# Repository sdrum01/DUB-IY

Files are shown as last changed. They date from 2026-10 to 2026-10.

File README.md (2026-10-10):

# DUB-IY Dub Siren with RP2040 CPU

## Repository to collect electronic and CAD/CAM Stuff

This repository belongs to the project [*DUBSIREN_rp2040*](https://github.com/sdrum01/dubsiren_rp2040), whitch contains the firmware of the DUB-IY.

Dub sirens are simple synthesizers without VCA (Voltage Controlled Amplifier) or VCF (Voltage Controlled Filter), but usually with a VCO (Voltage Controlled Oscillator) modulated by an LFO (Low Frequency Generator).

Such sirens are typically built with analog circuits. The challenge, however, was to optimize the parameter storage of digital solutions, simplify the electronics and to make it hackable.

**DUB-IY** is based on a Raspberry Pi Pico with an RP2040 CPU. It is fast enough to emulate VCOs and LFOs and offers sufficient options for internal data storage.

The Dub siren creates an square wave signal with an adjustable duty cycle. The sound can be modulated by two LFOs and an envelope generator to modulate the timing parameter. 

Finally, the signal is perfected with an integrated echo effect. 

The following values can be adjusted using potentiometers and switches:

* LFO1 waveform
(square, triple square, triangle, sawtooth, pulse)
* LFO2 waveform (square, triangle, sawtooth)
* Oscillator base frequency
* LFO1 and LFO2 frequency
* LFO1 and LFO2 contribution (negative and positive)
* Timing envelope contribution
* Oscillator waveform duty cycle
* LFO start retriggering
* Delay time (echo)
* Feedback (echo)
* Overall volume

The combination of LFOs 1 and 2 already produces many experimental siren sounds,
but the timing envelope adds significantly more dynamics to the sound.

>[!NOTE]
   >
   >This is a non-profit project with no goal of making big money.
   >It's purely for fun, and we assume no liability!
   
## Waiting List

To reserve one device or PCB pls write me an email: dub-iy@sdrum.elementfx.com

## Documentation

Have a look into the short introduction on YouTube:

- [DUB-IY Introduction](https://youtu.be/Yc06HZqR8gg?si=ktLNwQYJj4XRiWYL)

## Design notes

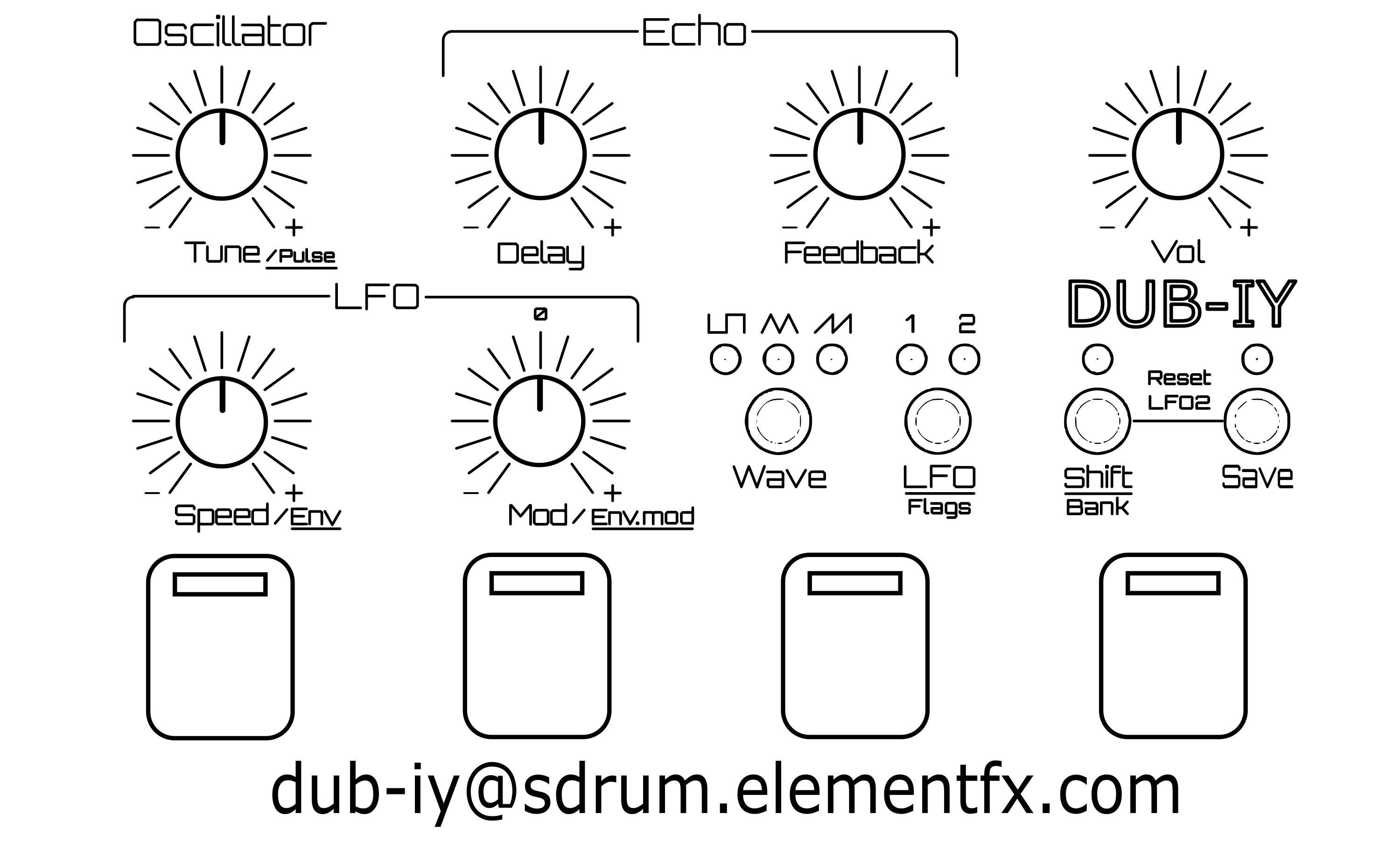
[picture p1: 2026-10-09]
CAD/DXF/Front_DUBIY_mit_Beschriftung_buisnesscard_v3.png

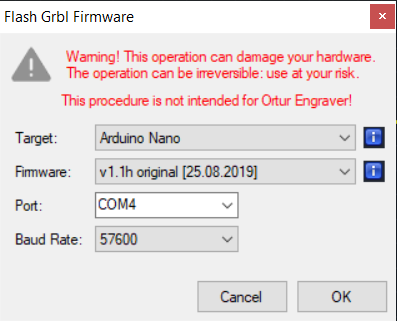
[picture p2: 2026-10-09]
CAD/CAM/LaserGRBL/flash_firmware.png

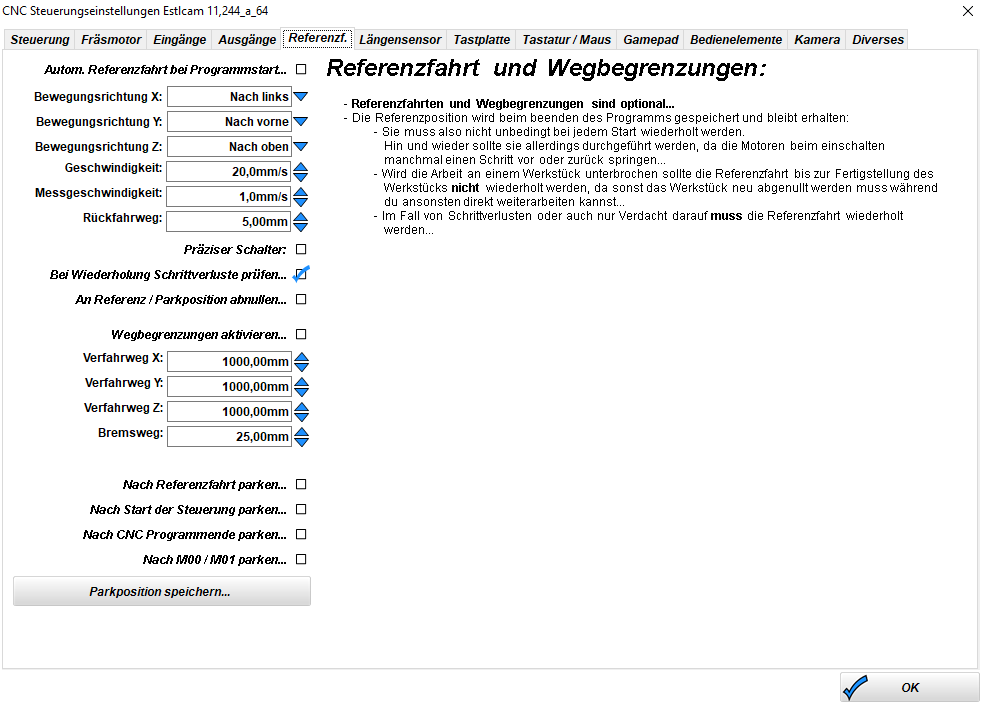
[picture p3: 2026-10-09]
CAD/CAM/Settings_Fräser_ref.png

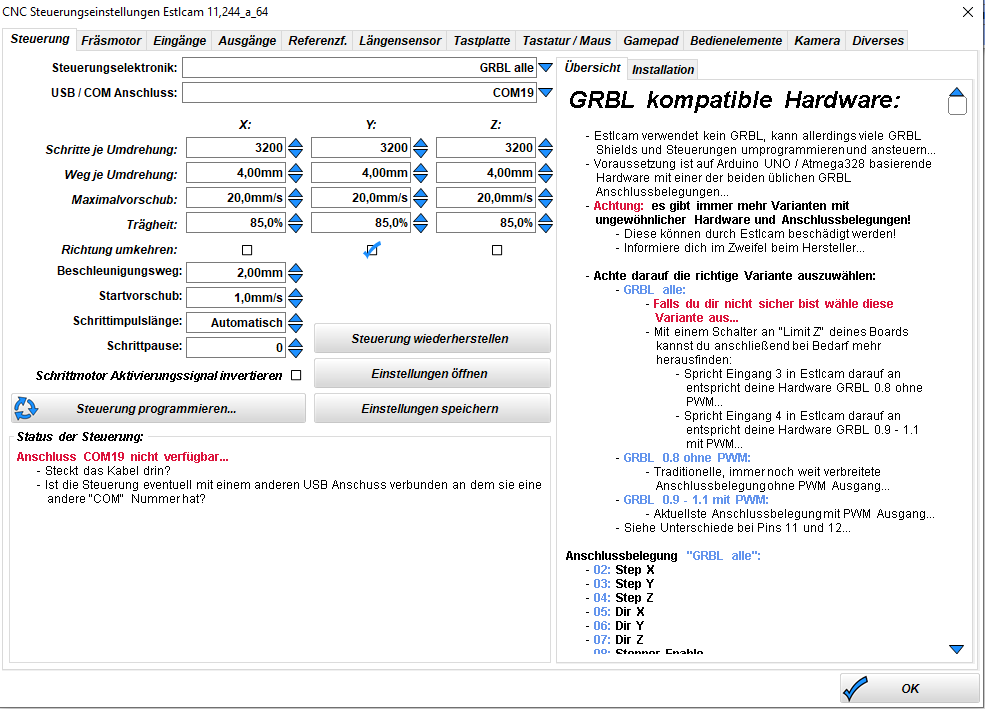
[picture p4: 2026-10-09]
CAD/CAM/Settings_Fräser.png

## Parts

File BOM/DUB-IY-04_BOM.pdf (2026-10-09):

Reference | Value | Datasheet Footprint | Qty
A1 | RaspberryPi-Pico | https://datasheets.raspberrypi.com/pico/pico-datasheet.pdf MCU_RaspberryPi_and_Boards:RPi_Pico_SMD_TH 1
C1,C8 | 100µ | ~ | Capacitor_SMD:CP_Elec_6.3x5.8 | 2
C2,C3,C4,C5,C6,C7,C10,C14,C15 | 100n | ~ | -- verschiedene Werte -- | 9
C9 | 47µ | ~ | Capacitor_SMD:CP_Elec_6.3x5.3 | 1
C11,C20 | 560pF | ~ | Capacitor_SMD:C_0805_2012Metric_Pad1.18x1.45mm_HandSolder 2
C12 | 3,9nF | ~ | Capacitor_SMD:C_0805_2012Metric_Pad1.18x1.45mm_HandSolder 1
C13 | 68nF | ~ | Capacitor_SMD:C_0805_2012Metric_Pad1.18x1.45mm_HandSolder 1
C16 | 3,3nF | ~ | Capacitor_SMD:C_0805_2012Metric_Pad1.18x1.45mm_HandSolder 1
C17,C18 | 4,7µ | ~ | Capacitor_Tantalum_SMD:CP_EIA-2012-12_Kemet-R_Pad1.30x1.05mm_HandSolder 2
C19 | 10n | ~ | Capacitor_SMD:C_0805_2012Metric_Pad1.18x1.45mm_HandSolder 1
C21,C23 | 10µ | ~ | Capacitor_SMD:CP_Elec_4x5.7 | 2
C22 | 82nF | ~ | Capacitor_SMD:C_0805_2012Metric_Pad1.18x1.45mm_HandSolder 1
C24 | 220n | ~ | Capacitor_SMD:C_1206_3216Metric 1
D1 | LED LFO2 | ~ | LED_THT:LED_D3.0mm | 1
D2 | LED LFO1 | ~ | LED_THT:LED_D3.0mm | 1
D3 | LED Shift1 | ~ | LED_THT:LED_D3.0mm | 1
D4 | LED Fire1 | ~ | LED_THT:LED_D3.0mm | 1
D5 | LED Fire2 | ~ | LED_THT:LED_D3.0mm | 1
D6 | LED Fire3 | ~ | LED_THT:LED_D3.0mm | 1
D7 | LED Fire4 | ~ | LED_THT:LED_D3.0mm | 1
D8 | LED_WF_Squ | ~ | LED_THT:LED_D3.0mm | 1
D9 | LED Shift2 | ~ | LED_THT:LED_D3.0mm | 1
D10 | LED_WF_Tri | ~ | LED_THT:LED_D3.0mm | 1
D11 | LED_WF_Saw | ~ | LED_THT:LED_D3.0mm | 1
D20 | SK110 | ~ | Diode_SMD:D_SMA-SMB_Universal_Handsoldering 1
J1 | AudioJack3_Ground ~ | Audiosockets:Jack_3.5mm_Ledino_KB3SPRS_Horizontal 1
J2 | Power Jack | ~ | Connector_BarrelJack:BarrelJack_GCT_DCJ200-10-A_Horizontal 1
R2,R3,R7,R8,R9,R10,R11,R12,R16,R17,R18 | 680 ~ | Resistor_SMD:R_1206_3216Metric 11
R4,R5,R6 | 1k | ~ | Resistor_SMD:R_1206_3216Metric | 3
R19,R27 | 4,7k | ~ | Resistor_SMD:R_1206_3216Metric | 2
R20,R21,R26,R28,R29,R30,RV1,RV2,RV3 | 10k | ~ | -- verschiedene Werte -- | 9
R22,R25 | 15k | ~ | Resistor_SMD:R_1206_3216Metric | 2
R23,RV4,RV5 | 100k | ~ | -- verschiedene Werte -- | 3
R24 | 5,6k | ~ | Resistor_SMD:R_1206_3216Metric | 1
RV6 | 50k | ~ | poti_alps:Potentiometer_Alps_RK09K_Single_Vertical 1
SW1 | LFO1/2 | ~ | Button_Switch_THT:SW_PUSH_6mm1
SW2 | Select LFO WaveForm~ | Button_Switch_THT:SW_PUSH_6mm1
SW3 | Fire4 | ~ | Button_Switch_THT:SW_PUSH_6mm1
SW4 | Fire3 | ~ | Button_Switch_THT:SW_PUSH_6mm1
SW5 | Fire2 | ~ | Button_Switch_THT:SW_PUSH_6mm1
SW6 | Fire1 | ~ | Button_Switch_THT:SW_PUSH_6mm1
SW7 | Shift2/Save | ~ | Button_Switch_THT:SW_PUSH_6mm1
SW8 | Shift1 / Select Bank | ~ | Button_Switch_THT:SW_PUSH_6mm1
U2 | PT2399 | Package_DIP:DIP-16_W7.62mm_Socket_LongPads 1
U3 | L7805 | http://www.st.com/content/ccc/resource/technical/document/datasheet/41/4f/b3/b0/12/d4/47/88/CD00000444.pdf/files/CD00000444.pdf/jcr:content/translations/en.CD0000044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 Package_TO_SOT_SMD:TO-252-3_TabPin2 1
Netzteil 12V 0,5A | | | | 1
PCB | | | | 1
Adapter Klinke 3,5mm-6,3mm | | | | 10

DNP Reichelt | EK | EK Summe
RASP PI PICO H | 5,46 | 5,46
FT-V 100U 16 | 0,24 | 0,48
0,02 | 0,18
ELN RVS-16V470MU | 0,10 | 0,10
0,02 | 0,04
0,02 | 0,02
0,02 | 0,02
0,02 | 0,02
KEM X5R0805 4,7U | 0,10 | 0,20
0,02 | 0,02
SMD ELKO 10/16 | 0,04 | 0,08
0,02 | 0,02
0,02 | 0,02
3004Y1D-EHC-B (https://www.reichelt.de/de/de/shop/produkt/led_3mm_bedrahtet_gelb_350_mcd_60_-361904) | 0,08 | 0,08 gelb
3004Y1D-EHC-B (https://www.reichelt.de/de/de/shop/produkt/led_3mm_bedrahtet_gelb_350_mcd_60_-361904) | 0,08 | 0,08 gelb
3004Y1D-EHC-B (https://www.reichelt.de/de/de/shop/produkt/led_3mm_bedrahtet_gelb_350_mcd_60_-361904) | 0,08 | 0,08 gelb
3034B2D-EHD-A | 0,08 | 0,08 blau
3034B2D-EHD-A | 0,08 | 0,08 blau
3034B2D-EHD-A | 0,08 | 0,08 blau
3034B2D-EHD-A | 0,08 | 0,08 blau
3004G6D-EHB-S (https://www.reichelt.de/de/de/shop/produkt/led_3mm_bedrahtet_gruen_200_mcd_60_-361906) | 0,08 | 0,08 grün
3004R2D-EPC-S (https://www.reichelt.de/de/de/shop/produkt/led_3mm_bedrahtet_rot_100_mcd_60_-361901) | 0,15 | 0,15 rot
3004G6D-EHB-S (https://www.reichelt.de/de/de/shop/produkt/led_3mm_bedrahtet_gruen_200_mcd_60_-361906) | 0,08 | 0,08 grün
3004G6D-EHB-S (https://www.reichelt.de/de/de/shop/produkt/led_3mm_bedrahtet_gruen_200_mcd_60_-361906) | 0,08 | 0,08 grün
0,02 | 0,02
EBS 35 | 0,36 | 0,36
CLIFF FCR681465 | 1,10 | 1,10
0,02 | 0,22
0,02 | 0,06
0,02 | 0,04
RK09K113-LIN10K | 0,99 | 8,91
0,02 | 0,04
RK09K113-LIN100K | 0,99 | 2,97
0,02 | 0,02
RK09K113-LIN50K | 0,99 | 0,99
OMR B3F-1002 | 0,29 | 0,29
OMR B3F-1002 | 0,29 | 0,29
RAFI 100.502 | 1,15 | 1,15
RAFI 100.502 | 1,15 | 1,15
RAFI 100.502 | 1,15 | 1,15
RAFI 100.502 | 1,15 | 1,15
OMR B3F-1002 | 0,29 | 0,29
OMR B3F-1002 | 0,29 | 0,29
4,00 | 4,00 CHINA
L78M05CDT STM | 0,21 | 0,21
EA1005BHES1201 oder
YS6V-1200500E | 7,00 | 7,00
10,00 | 10,00
2,00 | 20,00

incl. MWST
SUMME | 69,31 | 82,4789

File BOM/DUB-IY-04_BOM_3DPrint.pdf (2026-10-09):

Position Name | STL File | Filament Color | Filament Material QTY
1 | Body | DIYBody_V12.3.stl | Black | PLA | 1
2 | Body bottom | DIYBodyBottomSlim_V12.3.stl | Black | PLA | 1
3 | Functionsbuttons / Shift | DIYKnobShift_V12.2_8mm.stl | White | PLA | 4
4 | Fire Button | DIYKnobFire_V12.3.stl | White | PLA | 4
5 | Fire Button extension | DIYKnobFire - Stößel_V12.3_1.stl | White | PLA | 4
6 | Fire Button Inlay | DIYKnobFire - Inlay_V12.3.stl | White | PLA | 4
7 | stribe for Buttons | DIYBodyStreifen.stl | White or Black or whatever | PLA | 1
8 | Potiknob | PotiKnobV25.stl | Black | PLA | 6
9 | Potiknob Inlay | PotiKnob - Inlays_x10_V12.0.stl | Transparent | PLA | 6

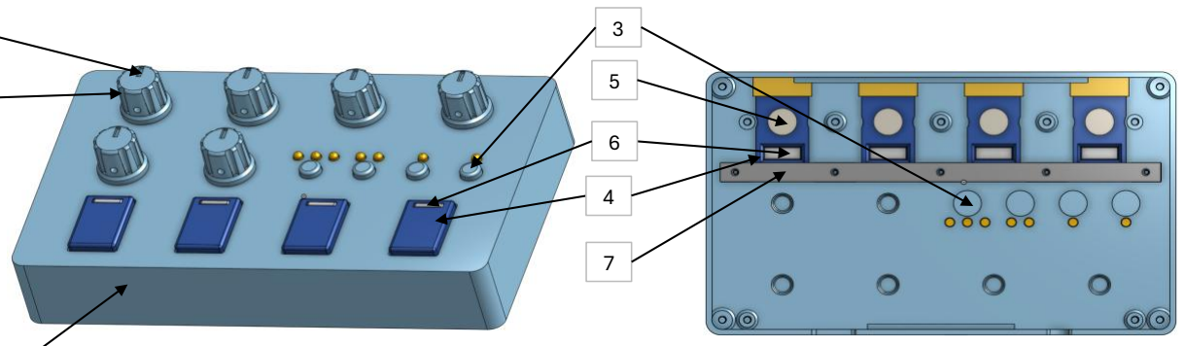
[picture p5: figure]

1 | 2

8

9

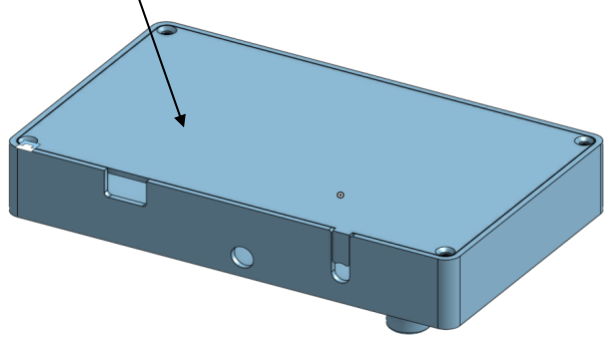
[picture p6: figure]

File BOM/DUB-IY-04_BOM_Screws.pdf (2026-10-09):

Reference | Name | Qty Bemerkung | Hersteller Partno. | Conrad Orderno. RS Online
| 1 Gewindestift M2 x 4mm | 6 für Potiknopf | Toolcraft TO-5370165 | 1790055 - NA431-965
2 Zylinderkopf Innensechskantschraube, Stahl schwarz passiviert, M1.6 x 0.35mm, 6mm 5 für Leiste | 304-17-406
| 3 Zylinderkopf Innensechskantschraube, Edelstahl A2 , M3 x 0.5mm, 6mm | 7 Befestigung PCB | | 303-95-067
| 4 Senkkopf Innensechskantschraube, Edelstahl DIN 7991 A4, M3 x 0.5mm, 8mm | 4 Gehäuseschraube | | 304-17-413

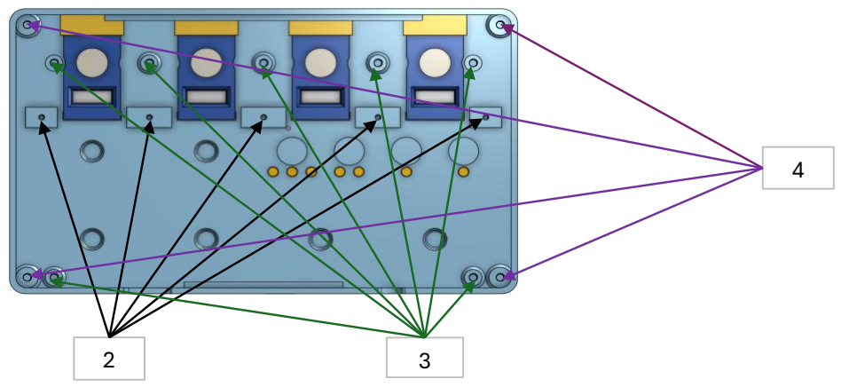
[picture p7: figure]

1

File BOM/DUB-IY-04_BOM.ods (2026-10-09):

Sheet: electronic
Reference | Value | Datasheet | Footprint | Qty | DNP | Reichelt | EK | EK Summe
A1 | RaspberryPi-Pico | https://datasheets.raspberrypi.com/pico/pico-datasheet.pdf | MCU_RaspberryPi_and_Boards:RPi_Pico_SMD_TH | 1 |  | RASP PI PICO H | 5,46 | 5,46
C1,C8 | 100µ | ~ | Capacitor_SMD:CP_Elec_6.3x5.8 | 2 |  | FT-V 100U 16 | 0,24 | 0,48
C2,C3,C4,C5,C6,C7,C10,C14,C15 | 100n | ~ | -- verschiedene Werte -- | 9 |  |  | 0,02 | 0,18
C9 | 47µ | ~ | Capacitor_SMD:CP_Elec_6.3x5.3 | 1 |  | ELN RVS-16V470MU | 0,10 | 0,10
C11,C20 | 560pF | ~ | Capacitor_SMD:C_0805_2012Metric_Pad1.18x1.45mm_HandSolder | 2 |  |  | 0,02 | 0,04
C12 | 3,9nF | ~ | Capacitor_SMD:C_0805_2012Metric_Pad1.18x1.45mm_HandSolder | 1 |  |  | 0,02 | 0,02
C13 | 68nF | ~ | Capacitor_SMD:C_0805_2012Metric_Pad1.18x1.45mm_HandSolder | 1 |  |  | 0,02 | 0,02
C16 | 3,3nF | ~ | Capacitor_SMD:C_0805_2012Metric_Pad1.18x1.45mm_HandSolder | 1 |  |  | 0,02 | 0,02
C17,C18 | 4,7µ | ~ | Capacitor_Tantalum_SMD:CP_EIA-2012-12_Kemet-R_Pad1.30x1.05mm_HandSolder | 2 |  | KEM X5R0805 4,7U | 0,10 | 0,20
C19 | 10n | ~ | Capacitor_SMD:C_0805_2012Metric_Pad1.18x1.45mm_HandSolder | 1 |  |  | 0,02 | 0,02
C21,C23 | 10µ | ~ | Capacitor_SMD:CP_Elec_4x5.7 | 2 |  | SMD ELKO 10/16 | 0,04 | 0,08
C22 | 82nF | ~ | Capacitor_SMD:C_0805_2012Metric_Pad1.18x1.45mm_HandSolder | 1 |  |  | 0,02 | 0,02
C24 | 220n | ~ | Capacitor_SMD:C_1206_3216Metric | 1 |  |  | 0,02 | 0,02
D1 | LED LFO2 | ~ | LED_THT:LED_D3.0mm | 1 |  | 3004Y1D-EHC-B (https://www.reichelt.de/de/de/shop/produkt/led_3mm_bedrahtet_gelb_350_mcd_60_-361904) | 0,08 | 0,08 | gelb
D2 | LED LFO1 | ~ | LED_THT:LED_D3.0mm | 1 |  | 3004Y1D-EHC-B (https://www.reichelt.de/de/de/shop/produkt/led_3mm_bedrahtet_gelb_350_mcd_60_-361904) | 0,08 | 0,08 | gelb
D3 | LED Shift1 | ~ | LED_THT:LED_D3.0mm | 1 |  | 3004Y1D-EHC-B (https://www.reichelt.de/de/de/shop/produkt/led_3mm_bedrahtet_gelb_350_mcd_60_-361904) | 0,08 | 0,08 | gelb
D4 | LED Fire1 | ~ | LED_THT:LED_D3.0mm | 1 |  | 3034B2D-EHD-A | 0,08 | 0,08 | blau
D5 | LED Fire2 | ~ | LED_THT:LED_D3.0mm | 1 |  | 3034B2D-EHD-A | 0,08 | 0,08 | blau
D6 | LED Fire3 | ~ | LED_THT:LED_D3.0mm | 1 |  | 3034B2D-EHD-A | 0,08 | 0,08 | blau
D7 | LED Fire4 | ~ | LED_THT:LED_D3.0mm | 1 |  | 3034B2D-EHD-A | 0,08 | 0,08 | blau
D8 | LED_WF_Squ | ~ | LED_THT:LED_D3.0mm | 1 |  | 3004G6D-EHB-S (https://www.reichelt.de/de/de/shop/produkt/led_3mm_bedrahtet_gruen_200_mcd_60_-361906) | 0,08 | 0,08 | grün
D9 | LED Shift2 | ~ | LED_THT:LED_D3.0mm | 1 |  | 3004R2D-EPC-S (https://www.reichelt.de/de/de/shop/produkt/led_3mm_bedrahtet_rot_100_mcd_60_-361901) | 0,15 | 0,15 | rot
D10 | LED_WF_Tri | ~ | LED_THT:LED_D3.0mm | 1 |  | 3004G6D-EHB-S (https://www.reichelt.de/de/de/shop/produkt/led_3mm_bedrahtet_gruen_200_mcd_60_-361906) | 0,08 | 0,08 | grün
D11 | LED_WF_Saw | ~ | LED_THT:LED_D3.0mm | 1 |  | 3004G6D-EHB-S (https://www.reichelt.de/de/de/shop/produkt/led_3mm_bedrahtet_gruen_200_mcd_60_-361906) | 0,08 | 0,08 | grün
D20 | SK110 | ~ | Diode_SMD:D_SMA-SMB_Universal_Handsoldering | 1 |  |  | 0,02 | 0,02
J1 | AudioJack3_Ground | ~ | Audiosockets:Jack_3.5mm_Ledino_KB3SPRS_Horizontal | 1 |  | EBS 35 | 0,36 | 0,36
J2 | Power Jack | ~ | Connector_BarrelJack:BarrelJack_GCT_DCJ200-10-A_Horizontal | 1 |  | CLIFF FCR681465 | 1,10 | 1,10
R2,R3,R7,R8,R9,R10,R11,R12,R16,R17,R18 | 680 | ~ | Resistor_SMD:R_1206_3216Metric | 11 |  |  | 0,02 | 0,22
R4,R5,R6 | 1k | ~ | Resistor_SMD:R_1206_3216Metric | 3 |  |  | 0,02 | 0,06
R19,R27 | 4,7k | ~ | Resistor_SMD:R_1206_3216Metric | 2 |  |  | 0,02 | 0,04
R20,R21,R26,R28,R29,R30,RV1,RV2,RV3 | 10k | ~ | -- verschiedene Werte -- | 9 |  | RK09K113-LIN10K | 0,99 | 8,91
R22,R25 | 15k | ~ | Resistor_SMD:R_1206_3216Metric | 2 |  |  | 0,02 | 0,04
R23,RV4,RV5 | 100k | ~ | -- verschiedene Werte -- | 3 |  | RK09K113-LIN100K | 0,99 | 2,97
R24 | 5,6k | ~ | Resistor_SMD:R_1206_3216Metric | 1 |  |  | 0,02 | 0,02
RV6 | 50k | ~ | poti_alps:Potentiometer_Alps_RK09K_Single_Vertical | 1 |  | RK09K113-LIN50K | 0,99 | 0,99
SW1 | LFO1/2 | ~ | Button_Switch_THT:SW_PUSH_6mm | 1 |  | OMR B3F-1002 | 0,29 | 0,29
SW2 | Select LFO WaveForm | ~ | Button_Switch_THT:SW_PUSH_6mm | 1 |  | OMR B3F-1002 | 0,29 | 0,29
SW3 | Fire4 | ~ | Button_Switch_THT:SW_PUSH_6mm | 1 |  | RAFI 100.502 | 1,15 | 1,15
SW4 | Fire3 | ~ | Button_Switch_THT:SW_PUSH_6mm | 1 |  | RAFI 100.502 | 1,15 | 1,15
SW5 | Fire2 | ~ | Button_Switch_THT:SW_PUSH_6mm | 1 |  | RAFI 100.502 | 1,15 | 1,15
SW6 | Fire1 | ~ | Button_Switch_THT:SW_PUSH_6mm | 1 |  | RAFI 100.502 | 1,15 | 1,15
SW7 | Shift2/Save | ~ | Button_Switch_THT:SW_PUSH_6mm | 1 |  | OMR B3F-1002 | 0,29 | 0,29
SW8 | Shift1 / Select Bank | ~ | Button_Switch_THT:SW_PUSH_6mm | 1 |  | OMR B3F-1002 | 0,29 | 0,29
U2 | PT2399 |  | Package_DIP:DIP-16_W7.62mm_Socket_LongPads | 1 |  |  | 4,00 | 4,00 | CHINA
U3 | L7805 | http://www.st.com/content/ccc/resource/technical/document/datasheet/41/4f/b3/b0/12/d4/47/88/CD00000444.pdf/files/CD00000444.pdf/jcr:content/translations/en.CD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 | Package_TO_SOT_SMD:TO-252-3_TabPin2 | 1 |  | L78M05CDT STM | 0,21 | 0,21
Power Supply 12V 0,5A |  |  |  | 1 |  | EA1005BHES1201 oder YS6V-1200500E | 7,00 | 7,00
PCB |  |  |  | 1 |  |  | 10,00 | 10,00
Adapter Klinke 3,5mm-6,3mm |  |  |  | 10 |  |  | 2,00 | 20,00
 |  |  |  |  |  |  |  |  | incl. MWST
 |  |  |  |  |  |  | SUMME | 69,31 | 82,4789

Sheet: Screws
Reference | Name | Qty | Bemerkung | Hersteller Partno. | Conrad Orderno. | RS Online
1 | Gewindestift M2 x 4mm | 6 | für Potiknopf | Toolcraft TO-5370165 | 1790055 - NA | 431-965
2 | Zylinderkopf Innensechskantschraube, Stahl schwarz passiviert, M1.6 x 0.35mm, 6mm | 5 | für Leiste |  |  | 304-17-406
3 | Zylinderkopf Innensechskantschraube, Edelstahl A2 , M3 x 0.5mm, 6mm | 7 | Befestigung PCB |  |  | 303-95-067
4 | Senkkopf Innensechskantschraube, Edelstahl DIN 7991 A4, M3 x 0.5mm, 8mm | 4 | Gehäuseschraube |  |  | 304-17-413
 | 4
 | 2 3
 | 1

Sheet: 3D-Print
Position | Name | STL File | Filament Color | Filament Material | QTY
1 | Body | DIYBody_V12.3.stl | Black | PLA | 1
2 | Body bottom | DIYBodyBottomSlim_V12.3.stl | Black | PLA | 1
3 | Functionsbuttons / Shift | DIYKnobShift_V12.2_8mm.stl | White | PLA | 4
4 | Fire Button | DIYKnobFire_V12.3.stl | White | PLA | 4
5 | Fire Button extension | DIYKnobFire - Stößel_V12.3_1.stl | White | PLA | 4
6 | Fire Button Inlay | DIYKnobFire - Inlay_V12.3.stl | White | PLA | 4
7 | stribe for Buttons | DIYBodyStreifen.stl | White or Black or whatever | PLA | 1
8 | Potiknob | PotiKnobV25.stl | Black | PLA | 6
9 | Potiknob Inlay | PotiKnob - Inlays_x10_V12.0.stl | Transparent | PLA | 6
9 |  | 3
 |  | 5
8
 |  | 6
 |  | 4
 |  | 7
1 | 2

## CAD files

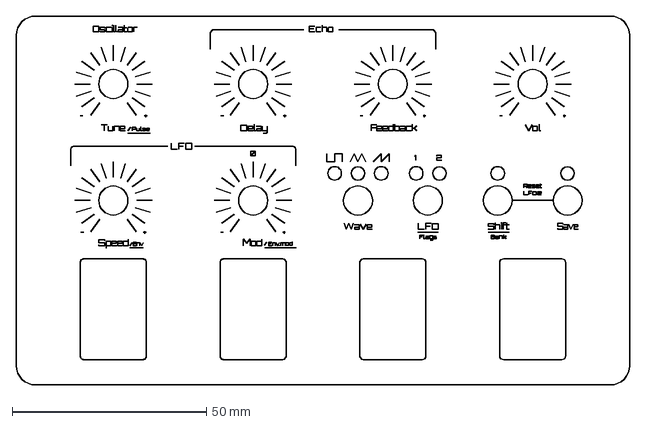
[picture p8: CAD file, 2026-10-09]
CAD/DXF/DIYBody - Frontplatte_EMS_1.dxf
158.0 x 95.0 mm

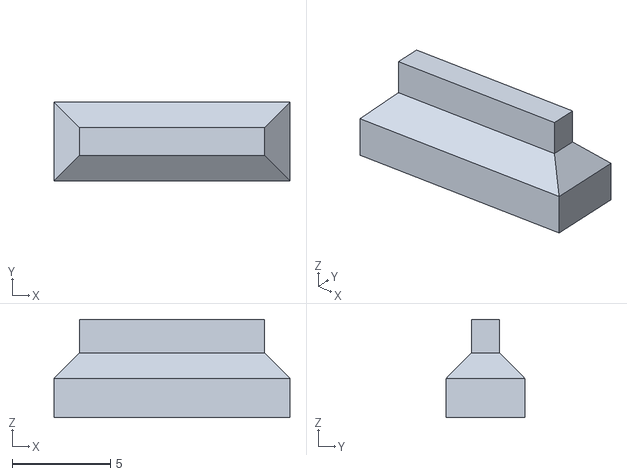
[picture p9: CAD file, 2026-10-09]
CAD/STL/10/DIYKnob Fire - Inlay square.stl
12.0 x 4.00 x 5.00

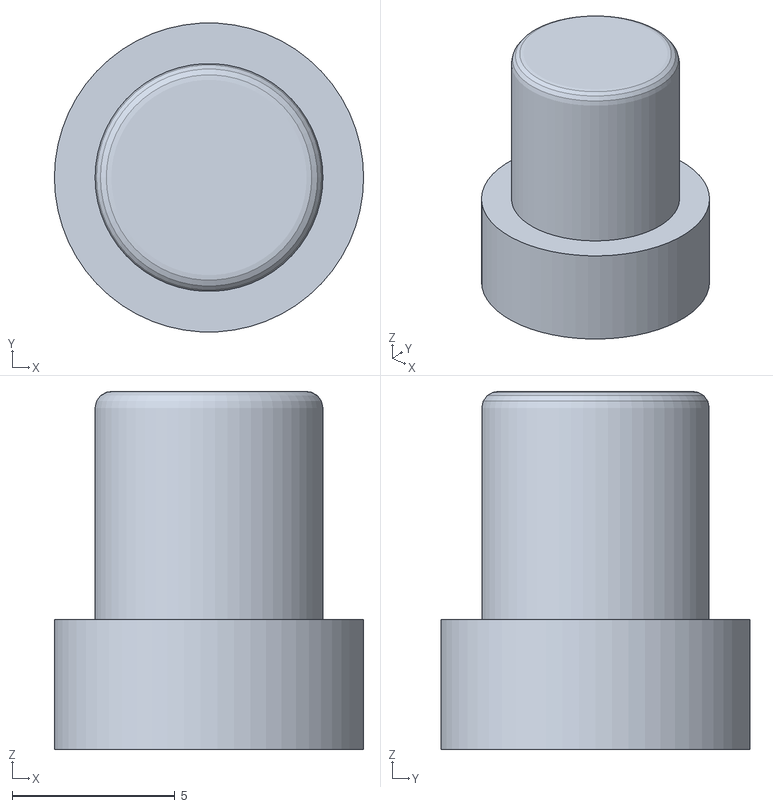
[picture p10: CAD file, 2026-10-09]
CAD/STL/11/DIYKnobShift_V11.3.stl
9.50 x 9.49 x 11.0

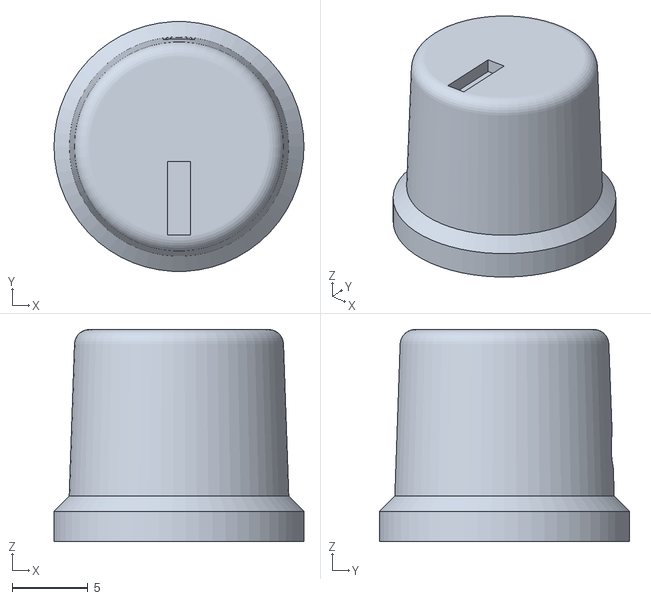
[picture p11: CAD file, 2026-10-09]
CAD/STL/25/PotiKnobV25.stl
16.5 x 16.5 x 14.0

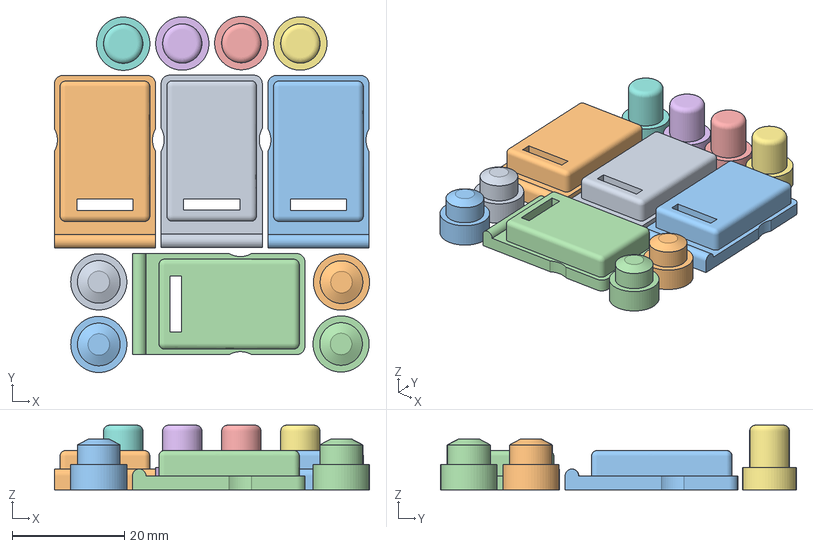
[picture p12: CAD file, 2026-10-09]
CAD/STL/CR10_DIYKnob_V12.3.3mf
56.1 x 63.4 x 11.5 mm
DIYKnobFire_V12.3.stl
DIYKnobFire_V12.3.stl(1)
DIYKnobFire_V12.3.stl(2)
DIYKnobFire_V12.3.stl(3)
DIYKnobShift_V12.2_8mm.stl
DIYKnobShift_V12.2_8mm.stl(1)
DIYKnobShift_V12.2_8mm.stl(2)
DIYKnobShift_V12.2_8mm.stl(3)
DIYKnobFire - Stößel_V12.3.stl
DIYKnobFire - Stößel_V12.3.stl(1)
DIYKnobFire - Stößel_V12.3.stl(2)
DIYKnobFire - Stößel_V12.3.stl(3)

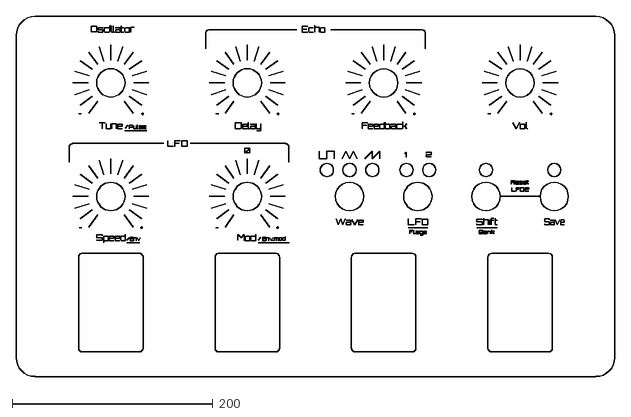
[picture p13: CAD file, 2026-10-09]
CAD/DXF/DIYBody - Frontplatte_EMS.dxf
597.2 x 359.1

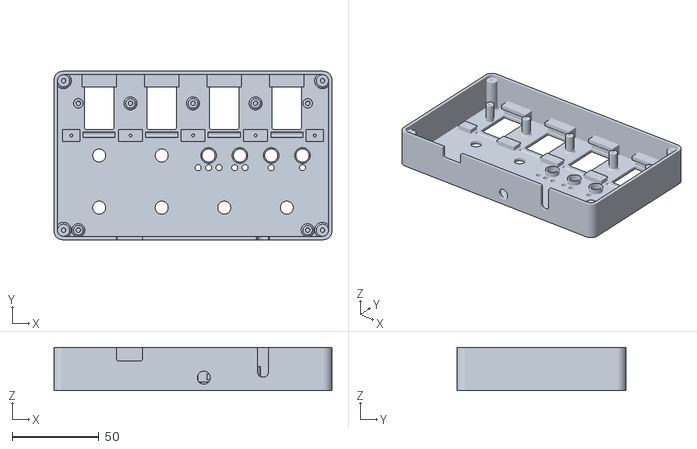
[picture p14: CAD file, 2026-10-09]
CAD/STL/11/DIYBody_V11.1.stl
160.0 x 97.0 x 25.0

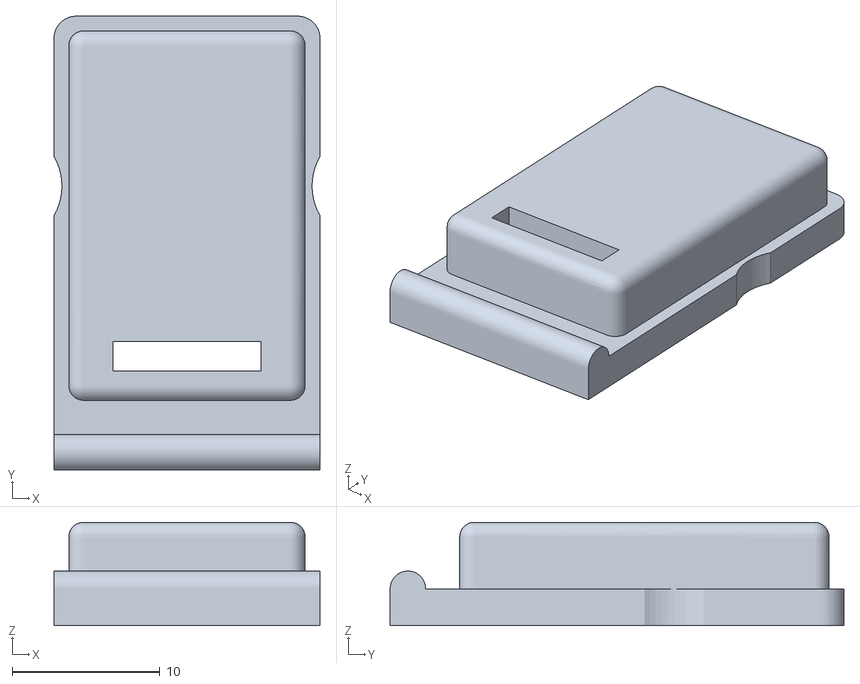
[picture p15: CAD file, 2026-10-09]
CAD/STL/12/DIYKnobFire_V12.3.stl
18.0 x 30.7 x 7.00

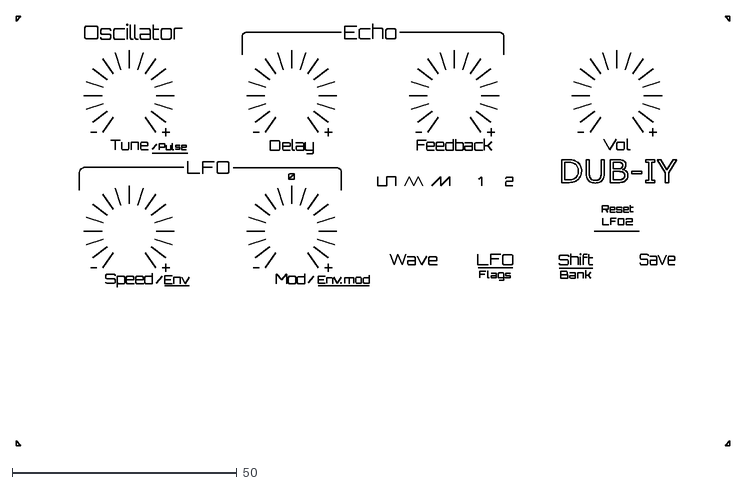
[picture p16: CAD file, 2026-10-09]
CAD/DXF/Frontplatte_EMS_grosse_schriftt_engrave_logo_lasergrbl.dxf
158.9 x 95.5

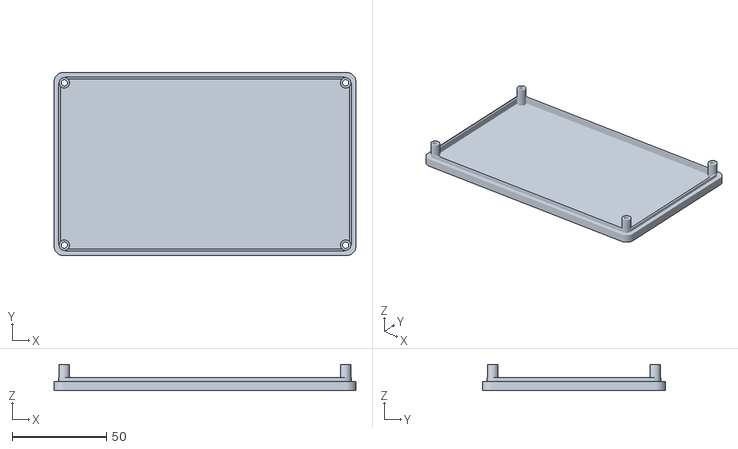
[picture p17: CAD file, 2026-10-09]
CAD/STL/10/DIYDeckel_V10.1.stl
160.0 x 97.0 x 14.0

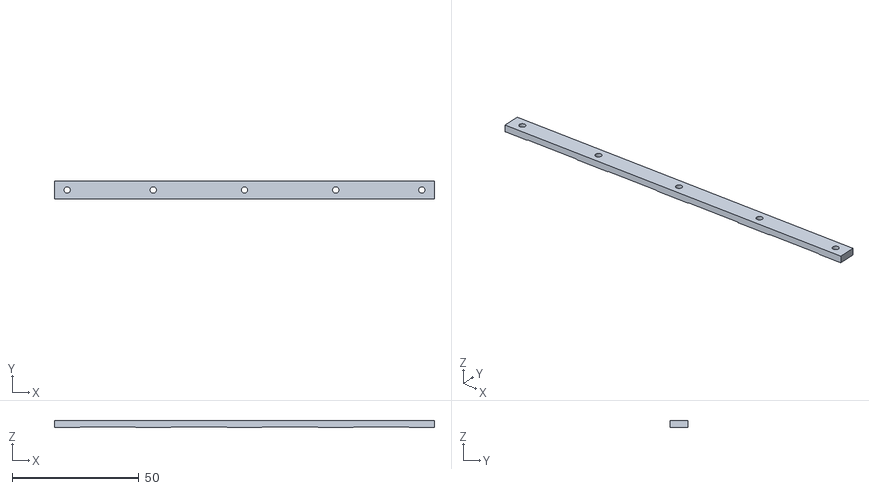
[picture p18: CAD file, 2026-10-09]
CAD/STL/11/DIYStreifen_V11.3.stl
150.0 x 7.00 x 2.70

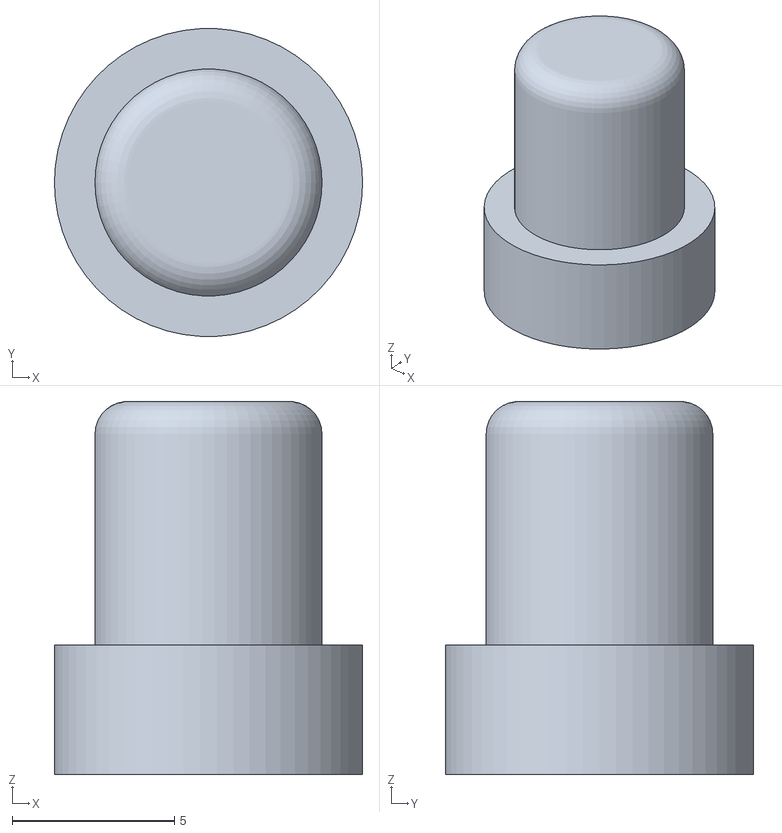
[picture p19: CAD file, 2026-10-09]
CAD/STL/12/DIYKnobShift_V12.2_8mm.stl
9.50 x 9.49 x 11.5

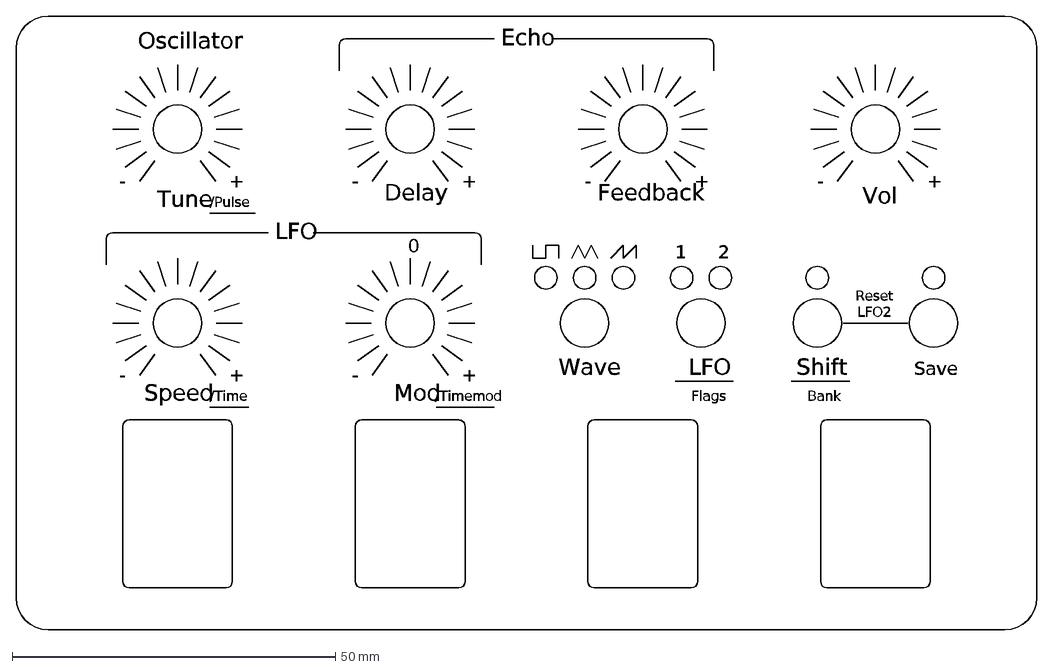
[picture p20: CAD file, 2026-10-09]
CAD/DXF/DIYBody - Frontplatte.dxf
-
+
0
2
1
Speed
Mod
/Time
/Timemod
Wave
LFO
Shift
Tune
Delay
Feedback
/Pulse
Bank
Save
Flags
Reset LFO2
Oscillator
Vol
Echo

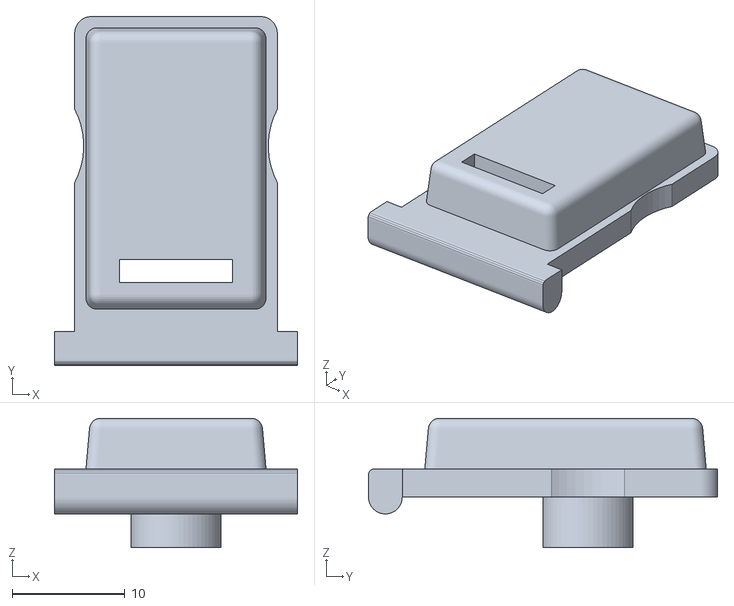
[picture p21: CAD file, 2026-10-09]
CAD/STL/10/DIYKnobFireSquare_V10.1.stl
21.6 x 31.0 x 11.5

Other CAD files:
CAD/STL/10/DIYKnobShift_V10.1.stl
CAD/STL/11/DIYDeckel_V11.4_5mm.stl
CAD/STL/12/DIYBodyBottomSlim_V12.3.stl
CAD/DXF/DIYBody - Frontplatte_EMS_grosse_schrift.dxf
CAD/STL/10/DIYBody_V10.2.stl
CAD/STL/10/DIYStreifen_V10.1.stl
CAD/STL/11/DIYBody - Rahmen.stl
CAD/STL/11/DIYDeckel_V11.1_10mm.stl
CAD/STL/11/DIYDeckel_V11.4_15mm.stl
CAD/STL/11/DIYKnobFireInlaysquare_V11.1.stl
CAD/STL/11/DIYKnobFireStößel_V11.2.stl
CAD/STL/11/DIYKnobFireStößel_V11.3.stl
CAD/STL/11/DIYKnobFiresquare_V11.3.stl
CAD/STL/11/PotiKnob_V11.6.stl
CAD/STL/11/PotiKnob_inlay_V11.6.stl
CAD/STL/12/DIYBodyBottomSlim_V12.1.stl
CAD/STL/12/DIYBodyStreifen.stl
CAD/STL/12/DIYBody_V12.0.stl
CAD/STL/12/DIYBody_V12.2.stl
CAD/STL/12/DIYBody_V12.3.stl
CAD/STL/12/DIYKnobFire - Inlay_V12.3.stl
CAD/STL/12/DIYKnobFire - Stößel_V12.3.stl
CAD/STL/12/DIYKnobFire - Stößel_V12.3_1.stl
CAD/STL/12/PotiKnob - Inlays_x10_V12.0.stl
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

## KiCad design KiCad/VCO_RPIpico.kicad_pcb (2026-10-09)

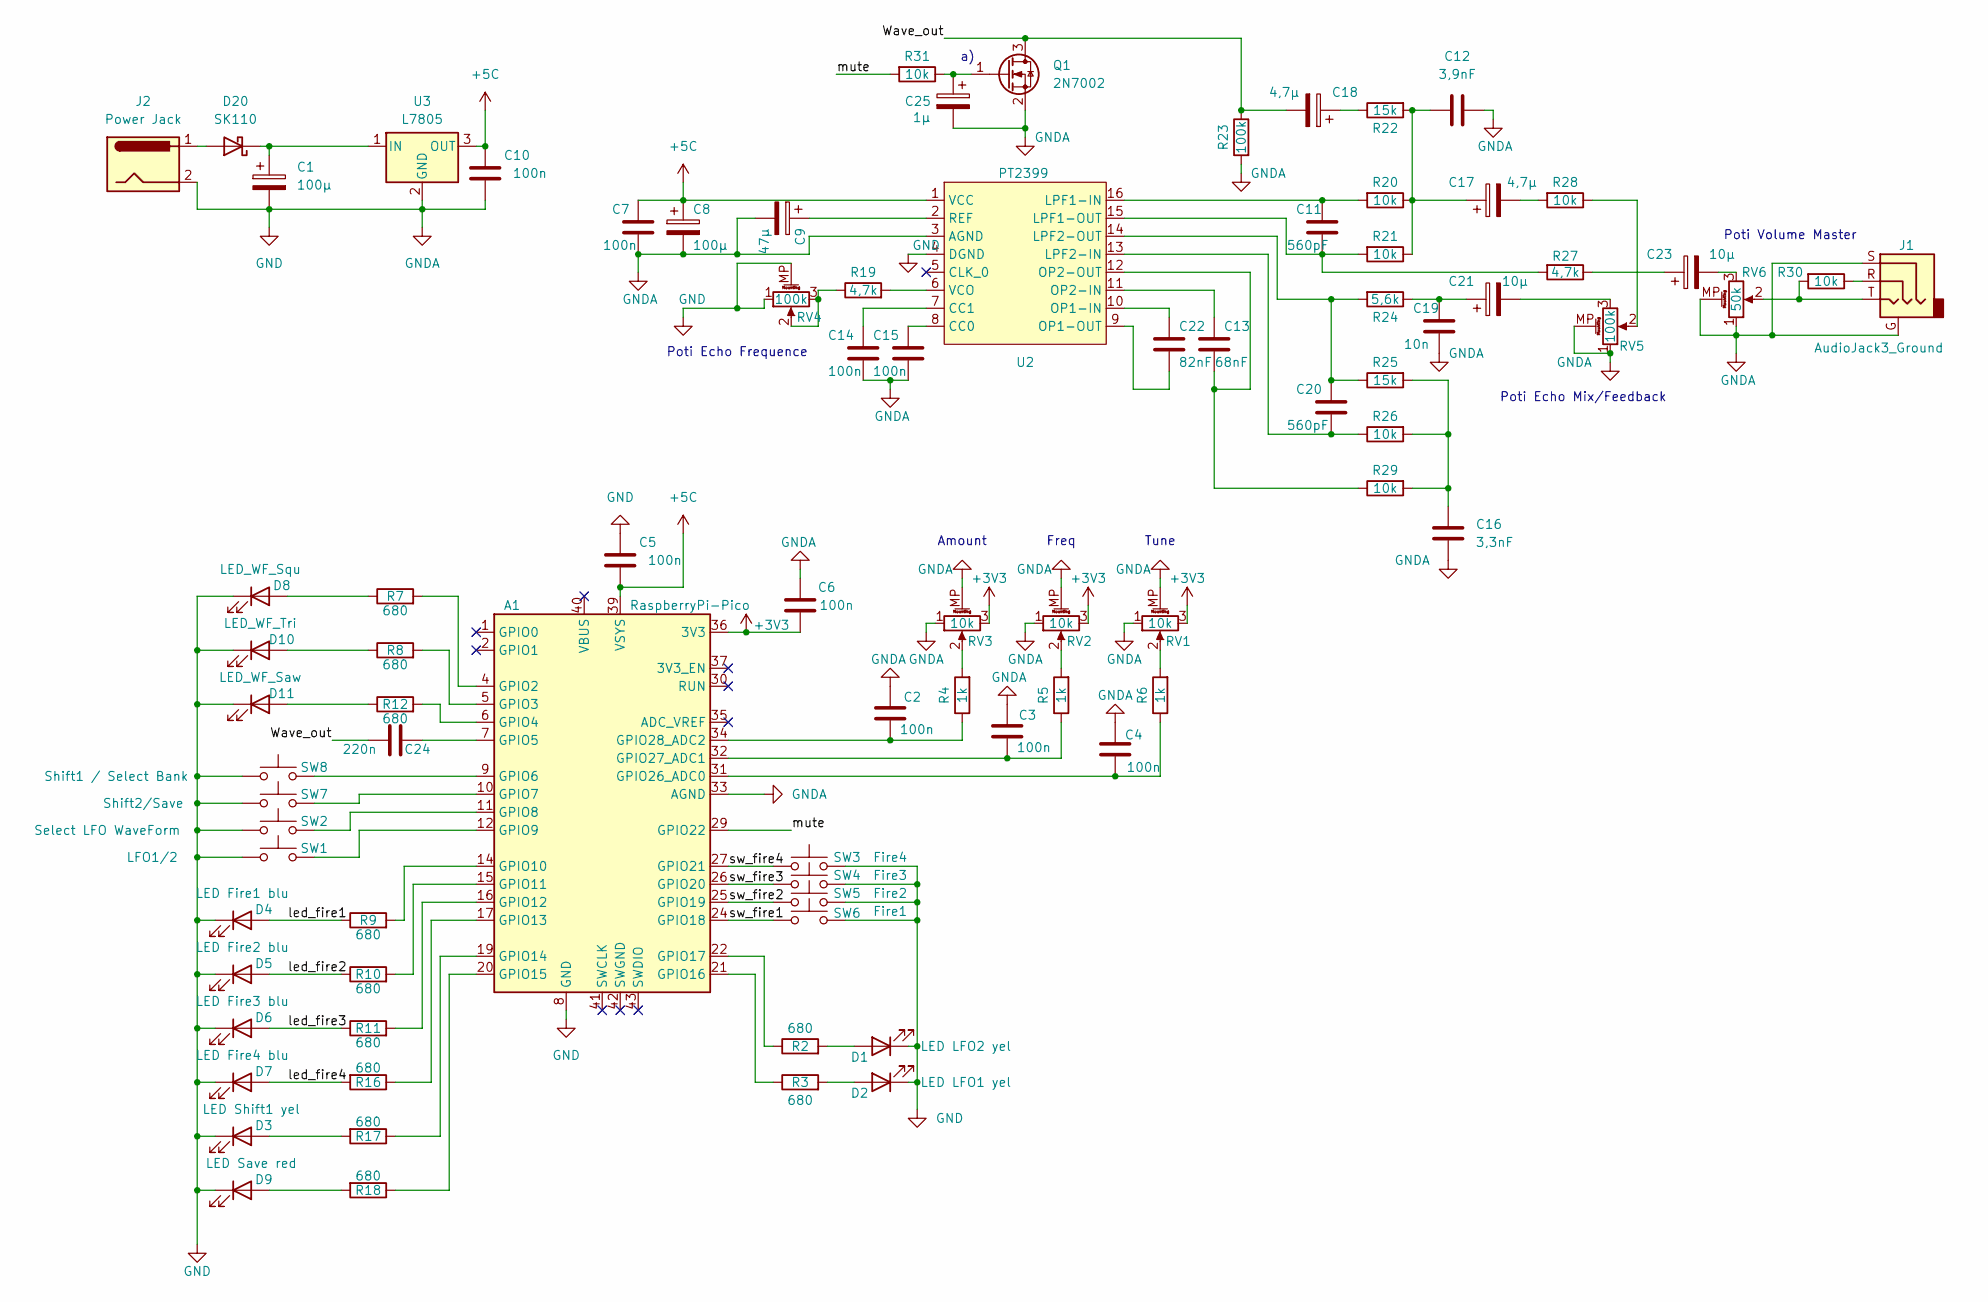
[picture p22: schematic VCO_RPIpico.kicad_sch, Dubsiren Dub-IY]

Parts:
A1: RaspberryPi-Pico; RPi_Pico_SMD_TH
C1, C8: 100µ; CP_Elec_6.3x5.8
C2, C3, C4, C5, C6, C7: 100n; C_1206_3216Metric
C9: 47µ; CP_Elec_6.3x5.3
C10, C14, C15: 100n; C_0805_2012Metric_Pad1.18x1.45mm_HandSolder
C11, C20: 560pF; C_0805_2012Metric_Pad1.18x1.45mm_HandSolder
C12: 3,9nF; C_0805_2012Metric_Pad1.18x1.45mm_HandSolder
C13: 68nF; C_0805_2012Metric_Pad1.18x1.45mm_HandSolder
C16: 3,3nF; C_0805_2012Metric_Pad1.18x1.45mm_HandSolder
C17, C18: 4,7µ; CP_EIA-2012-12_Kemet-R_Pad1.30x1.05mm_HandSolder
C19: 10n; C_0805_2012Metric_Pad1.18x1.45mm_HandSolder
C21, C23: 10µ; CP_Elec_4x5.7
C22: 82nF; C_0805_2012Metric_Pad1.18x1.45mm_HandSolder
C24: 220n; C_1206_3216Metric
C25: 1µ; CP_EIA-2012-12_Kemet-R_Pad1.30x1.05mm_HandSolder
D1: LED LFO2 yel; LED_D3.0mm
D2: LED LFO1 yel; LED_D3.0mm
D3: LED Shift1 yel; LED_D3.0mm
D4: LED Fire1 blu; LED_D3.0mm
D5: LED Fire2 blu; LED_D3.0mm
D6: LED Fire3 blu; LED_D3.0mm
D7: LED Fire4 blu; LED_D3.0mm
D8: LED_WF_Squ; LED_D3.0mm
D9: LED Save red; LED_D3.0mm
D10: LED_WF_Tri; LED_D3.0mm
D11: LED_WF_Saw; LED_D3.0mm
D20: SK110; D_SMA-SMB_Universal_Handsoldering
J1: AudioJack3_Ground; Jack_6.35mm_Neutrik_NMJ6HFD2_Horizontal
J2: Power Jack; BarrelJack_GCT_DCJ200-10-A_Horizontal
Q1: 2N7002; SOT-23
R2, R3, R7, R8, R9, R10, R11, R12, R16, R17, R18: 680; R_1206_3216Metric
R4, R5, R6: 1k; R_1206_3216Metric
R19, R27: 4,7k; R_1206_3216Metric
R20, R21, R26, R28, R29, R30, R31: 10k; R_1206_3216Metric
R22, R25: 15k; R_1206_3216Metric
R23: 100k; R_1206_3216Metric
R24: 5,6k; R_1206_3216Metric
RV1, RV2, RV3: 10k; Potentiometer_Alps_RK09K_Single_Vertical
RV4, RV5: 100k; Potentiometer_Alps_RK09K_Single_Vertical
RV6: 50k; Potentiometer_Alps_RK09K_Single_Vertical
SW1: LFO1/2; SW_PUSH_6mm
SW2: Select LFO WaveForm; SW_PUSH_6mm
SW3: Fire4; SW_PUSH_6mm
SW4: Fire3; SW_PUSH_6mm
SW5: Fire2; SW_PUSH_6mm
SW6: Fire1; SW_PUSH_6mm
SW7: Shift2/Save; SW_PUSH_6mm
SW8: Shift1 / Select Bank; SW_PUSH_6mm
U2: PT2399; DIP-16_W7.62mm_Socket_LongPads
U3: L7805; TO-252-3_TabPin2

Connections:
+3V3: A1.36 (3V3), C6.2, RV1.3, RV2.3, RV3.3
+5C: A1.39 (VSYS), C5.2, C7.1, C8.1, C10.1, U2.1 (VCC), U3.3 (OUT)
/Wave_out: C18.2, C24.1, Q1.3 (D), R23.1
/led_fire1: D4.2 (A), R9.1
/led_fire2: D5.2 (A), R10.1
/led_fire3: D6.2 (A), R11.1
/led_fire4: D7.2 (A), R16.2
/sw_fire1: A1.24 (GPIO18), SW6.1
/sw_fire2: A1.25 (GPIO19), SW5.1
/sw_fire3: A1.26 (GPIO20), SW4.1
/sw_fire4: A1.27 (GPIO21), SW3.1
GND: A1.3 (GND), A1.8 (GND), A1.13 (GND), A1.18 (GND), A1.23 (GND), A1.28 (GND), A1.33 (AGND), A1.38 (GND), C1.2, C2.1, C3.1, C4.1, C5.1, C6.1, C7.2, C8.2, C9.2, C10.2, C12.1, C14.2, C15.2, C16.2, C19.2, C25.2, D1.1 (K), D2.1 (K), D3.1 (K), D4.1 (K), D5.1 (K), D6.1 (K), D7.1 (K), D8.1 (K), D9.1 (K), D10.1 (K), D11.1 (K), J1.G, J1.S, J2.2, Q1.2 (S), R23.2, RV1.1, RV1.MP (MountPin), RV2.1, RV2.MP (MountPin), RV3.1, RV3.MP (MountPin), RV4.1, RV4.MP (MountPin), RV5.1, RV5.MP (MountPin), RV6.1, RV6.MP (MountPin), SW1.1, SW2.1, SW3.2, SW4.2, SW5.2, SW6.2, SW7.1, SW8.1, U2.3 (AGND), U2.4 (DGND), U3.2 (GND)
unnamed: A1.4 (GPIO2), R7.2
unnamed: A1.5 (GPIO3), R8.2
unnamed: A1.6 (GPIO4), R12.2
unnamed: A1.7 (GPIO5), C24.2
unnamed: A1.9 (GPIO6), SW8.2
unnamed: A1.10 (GPIO7), SW7.2
unnamed: A1.11 (GPIO8), SW2.2
unnamed: A1.12 (GPIO9), SW1.2
unnamed: A1.14 (GPIO10), R9.2
unnamed: A1.15 (GPIO11), R10.2
unnamed: A1.16 (GPIO12), R11.2
unnamed: A1.17 (GPIO13), R16.1
unnamed: A1.19 (GPIO14), R17.1
unnamed: A1.20 (GPIO15), R18.1
unnamed: A1.21 (GPIO16), R3.1
unnamed: A1.22 (GPIO17), R2.1
unnamed: A1.31 (GPIO26_ADC0), C4.2, R6.1
unnamed: A1.32 (GPIO27_ADC1), C3.2, R5.1
unnamed: A1.34 (GPIO28_ADC2), C2.2, R4.1
unnamed: C12.2, C17.1, R20.1, R21.1, R22.2
unnamed: C16.1, R25.2, R26.2, R29.2
unnamed: C17.2, R28.2
unnamed: C18.1, R22.1
unnamed: C19.1, C21.1, R24.1
unnamed: C21.2, RV5.3
unnamed: C23.1, R27.1
unnamed: C23.2, RV6.3
unnamed: C25.1, Q1.1 (G), R31.1
unnamed: D1.2 (A), R2.2
unnamed: D2.2 (A), R3.2
unnamed: D3.2 (A), R17.2
unnamed: D8.2 (A), R7.1
unnamed: D9.2 (A), R18.2
unnamed: D10.2 (A), R8.1
unnamed: D11.2 (A), R12.1
unnamed: D20.2 (A), J2.1
unnamed: C1.1, D20.1 (K), U3.1 (IN)
unnamed: J1.R, R30.1
unnamed: J1.T, R30.2, RV6.2
unnamed: R4.2, RV3.2
unnamed: R5.2, RV2.2
unnamed: R6.2, RV1.2
unnamed: R19.1, RV4.2, RV4.3
unnamed: R28.1, RV5.2
unnamed: A1.29 (GPIO22), R31.2
unnamed: C15.1, U2.8 (CC0)
unnamed: C14.1, U2.7 (CC1)
unnamed: C11.1, R20.2, U2.16 (LPF1-IN)
unnamed: C11.2, R21.2, R27.2, U2.15 (LPF1-OUT)
unnamed: C20.2, R26.1, U2.13 (LPF2-IN)
unnamed: C20.1, R24.2, R25.1, U2.14 (LPF2-OUT)
unnamed: C22.1, U2.10 (OP1-IN)
unnamed: C22.2, U2.9 (OP1-OUT)
unnamed: C13.1, U2.11 (OP2-IN)
unnamed: C13.2, R29.1, U2.12 (OP2-OUT)
unnamed: C9.1, U2.2 (REF)
unnamed: R19.2, U2.6 (VCO)

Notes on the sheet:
Poti Echo Mix/Feedback
Freq
Poti Echo Frequence
Tune
Poti Volume Master
Amount

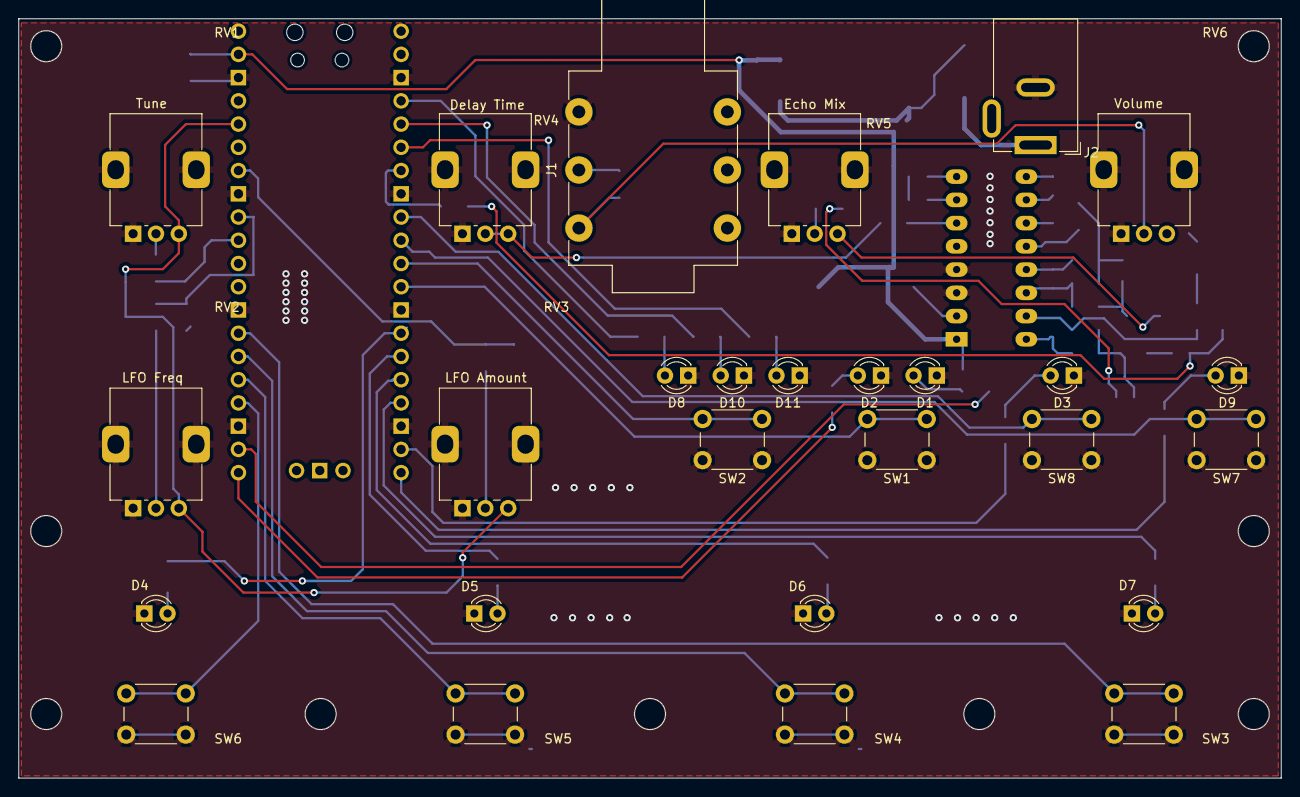
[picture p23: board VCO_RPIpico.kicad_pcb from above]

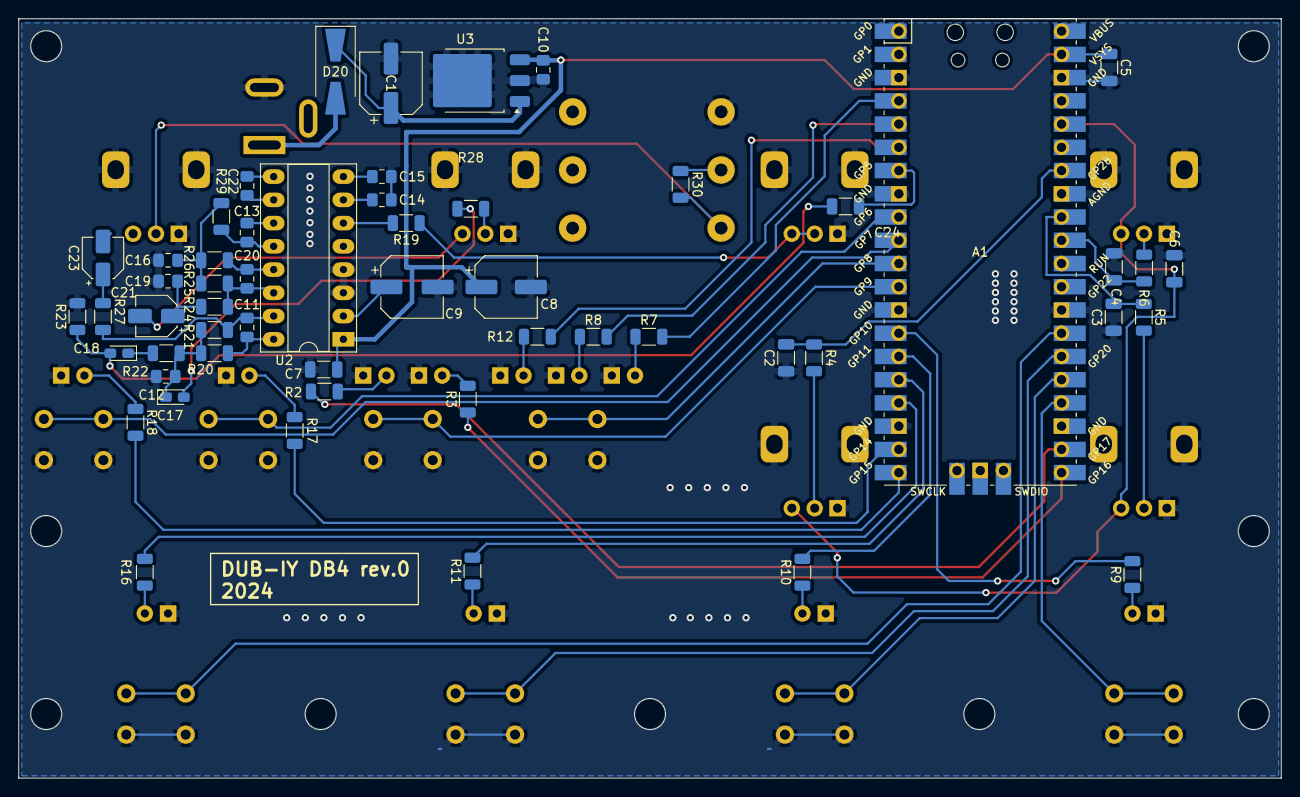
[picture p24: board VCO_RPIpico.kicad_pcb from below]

Board: 2 copper layers, 138.0 x 83.0 mm, 81 parts (54 on the bottom side), 67 nets.

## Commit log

2026-10-09 Display SSD1306 added
    [VCO_RPIpico.kicad_sch]
2026-10-10 change wiring on oled-display
    [VCO_RPIpico.kicad_sch]
